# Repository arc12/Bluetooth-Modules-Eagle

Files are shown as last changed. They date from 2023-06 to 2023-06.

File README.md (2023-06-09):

# Bluetooth Modules Eagle CAD Files
"Breakout" boards designed for HM10 and HM11 Bluetooth (BT) modules and pin-equivalent clones (etc) based on TI CC2540/2541 SoC.

These are intended to be usable for both breadboard prototyping and as modules for "finished" items (although admittedly in a DIY concept). Unlike breakouts on the open market, it is strictly a 3.3V approach. Both modules have a 5-pin header exposing the "debug" interface pins of the CC254x which can be used for loading new firmware (see notes below) and probably for actual debugging operations with a suitable IDE. The 5-pin header is semi-detached from the rest of the board due to a milled slot so that it can be cut off if not required (but pay attention to making sure the cut copper tracks don't have short-cuts.

As a "finished" item, the concept for the two boards differs:
- For the HM11 based board, the main header is arranged such that the central 6 pins match the pinout of popular USB-Serial boards based on CH340. The intention is that the BT board is plugged into the same header as is used for loading the firmware and is used to provide wireless serial output from a separate MCU and its associated sensors, or to provide serial input for control etc. Notice that there is a cuttable (and re-solderable) link adjacent to the header pins where the CH340 has DTR and RTS/CTS pins. Cut these if these are being used for bootloader control.
- For the HM10 based board, the scenario in mind is that the CC254x is used without a controlling MCU, with its I/O pins being used for various sensors or output connected to the main header.

Each board has one resistor and one capacitor as 1206 size SMD pads. These are optional; the capacitor is good practice for power supply and the resistor is intended for the "finished" scenarios.

## Changing Firmware
This is relevant to "clone" modules, although it may not work on all clones (definitely not if the CC254x is not genuine).

There are two fairly easy approaches:
- Using an ESP8266. See: https://github.com/Jason2866/CCLoader
- Using a Raspberry Pi. See: https://github.com/exotulip/CC2541-programmer

There are a lot of people who have essentially re-hashed the ESP8266 instructions and published online and the arduino forum is full of various accounts of success or failure. Using the boards presented here, with 3.3V native devices such as the RPi and ESP8266 should make life easier.

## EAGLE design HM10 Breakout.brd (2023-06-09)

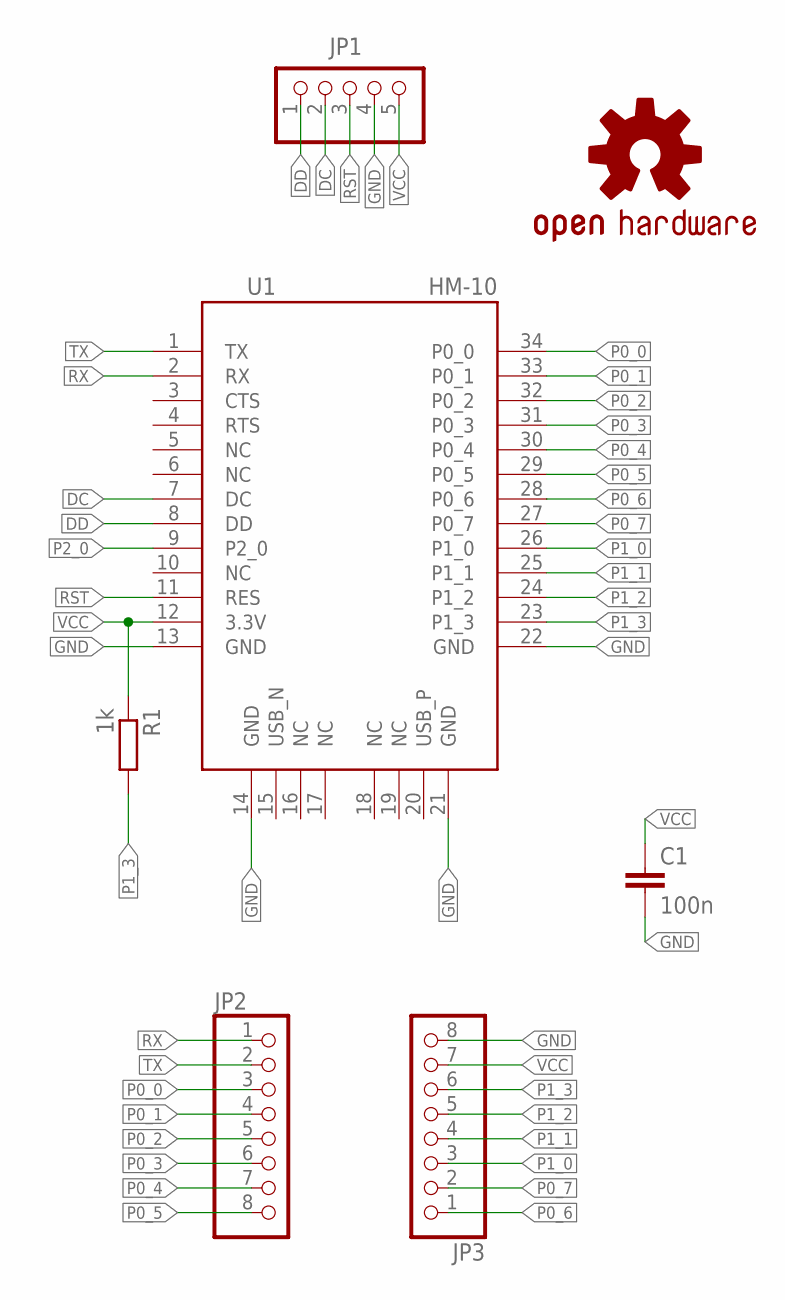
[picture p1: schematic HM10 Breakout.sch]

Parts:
C1: 100n; 1206
JP1: PINHD-1X5; 1X05
JP2, JP3: PINHD-1X8; 1X08
LOGO1: OSHW-LOGOM; OSHW-LOGO-M
R1: 1k; R1206
U1: HM-10

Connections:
DC: JP1.2, U1.7 (DC)
DD: JP1.1, U1.8 (DD)
GND: C1.2, JP1.4, JP3.8, U1.13 (GND), U1.14 (GND), U1.21 (GND), U1.22 (GND)
P0_0: JP2.3, U1.34 (P0_0)
P0_1: JP2.4, U1.33 (P0_1)
P0_2: JP2.5, U1.32 (P0_2)
P0_3: JP2.6, U1.31 (P0_3)
P0_4: JP2.7, U1.30 (P0_4)
P0_5: JP2.8, U1.29 (P0_5)
P0_6: JP3.1, U1.28 (P0_6)
P0_7: JP3.2, U1.27 (P0_7)
P1_0: JP3.3, U1.26 (P1_0)
P1_1: JP3.4, U1.25 (P1_1)
P1_2: JP3.5, U1.24 (P1_2)
P1_3: JP3.6, R1.2, U1.23 (P1_3)
P2_0: U1.9 (P2_0)
RST: JP1.3, U1.11 (RES)
RX: JP2.1, U1.2 (RX)
TX: JP2.2, U1.1 (TX)
VCC: C1.1, JP1.5, JP3.7, R1.1, U1.12 (3.3V)

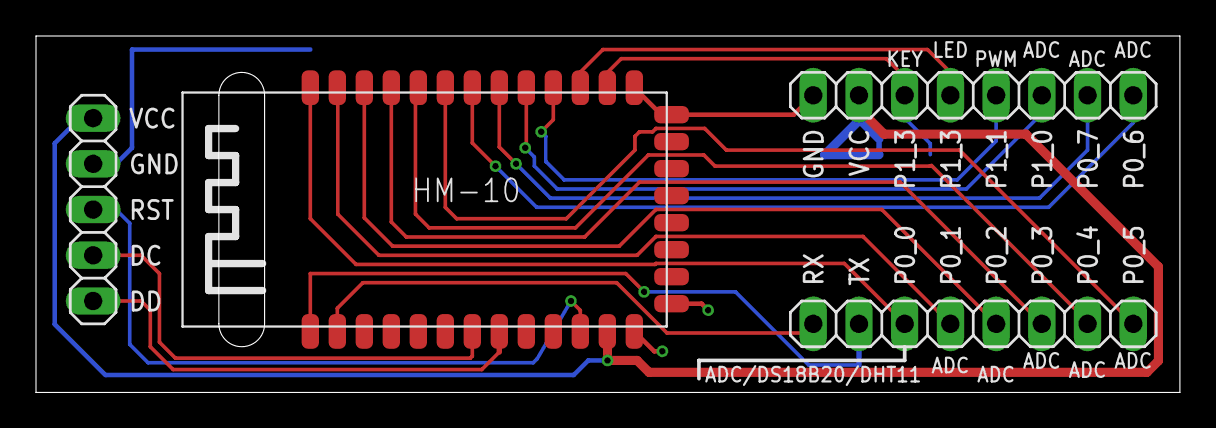
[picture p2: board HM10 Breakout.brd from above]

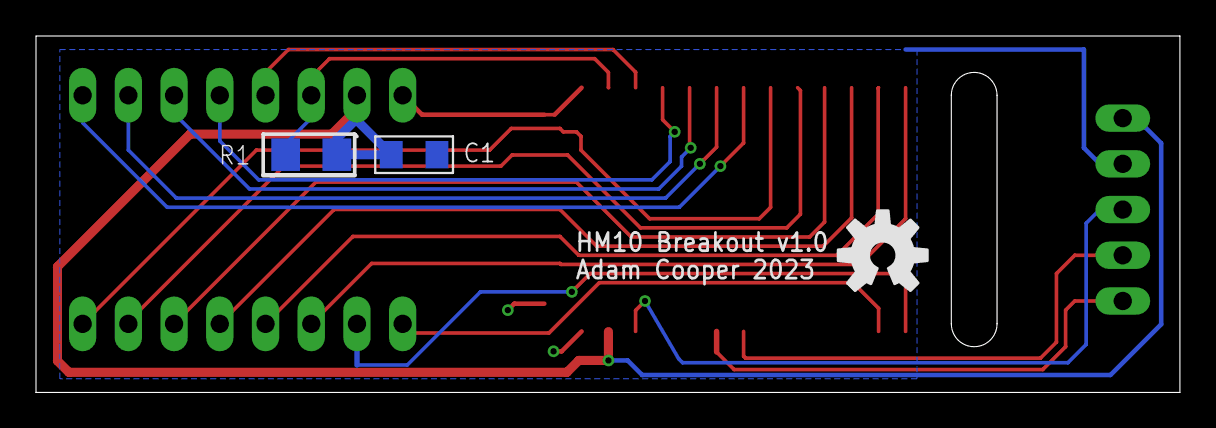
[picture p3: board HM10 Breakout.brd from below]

Board: 2 copper layers, 63.6 x 19.8 mm, 7 parts (3 on the bottom side), 19 nets.

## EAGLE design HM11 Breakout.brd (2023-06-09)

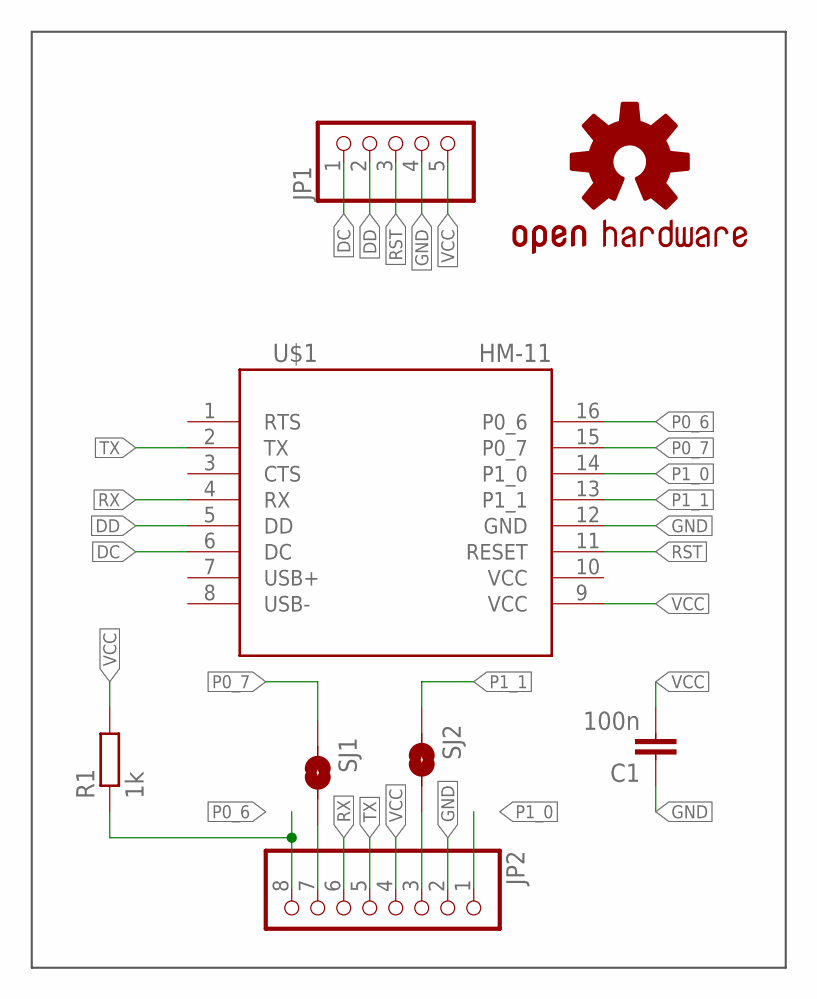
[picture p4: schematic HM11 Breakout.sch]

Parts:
C1: 100n; 1206
JP1: PINHD-1X5; 1X05
JP2: PINHD-1X8; 1X08
LOGO1: OSHW-LOGOM; OSHW-LOGO-M
R1: 1k; R1206
SJ1, SJ2: SOLDERJUMPERTRACE; SJ_2S-TRACE
U$1: HM-11

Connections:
DC: JP1.1, U$1.6 (DC)
DD: JP1.2, U$1.5 (DD)
GND: C1.1, JP1.4, JP2.2, U$1.12 (GND)
unnamed: JP2.7, SJ1.1
unnamed: JP2.3, SJ2.1
P0_6: JP2.8, R1.1, U$1.16 (P0_6)
P0_7: SJ1.2, U$1.15 (P0_7)
P1_0: JP2.1, U$1.14 (P1_0)
P1_1: SJ2.2, U$1.13 (P1_1)
RST: JP1.3, U$1.11 (RESET)
RX: JP2.6, U$1.4 (RX)
TX: JP2.5, U$1.2 (TX)
VCC: C1.2, JP1.5, JP2.4, R1.2, U$1.9 (VCC)

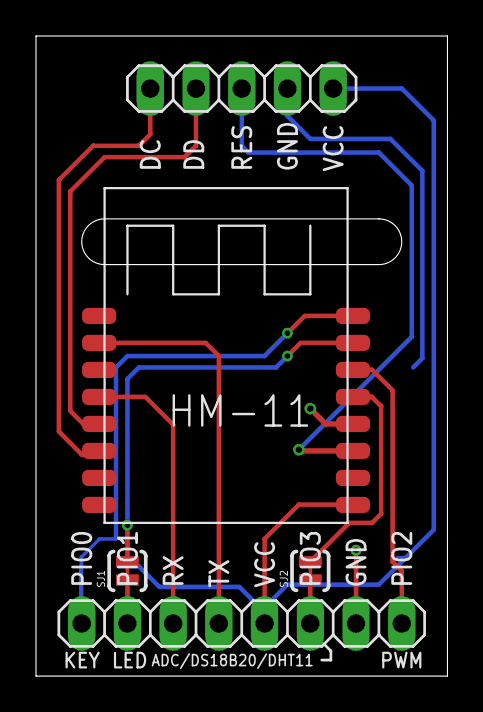
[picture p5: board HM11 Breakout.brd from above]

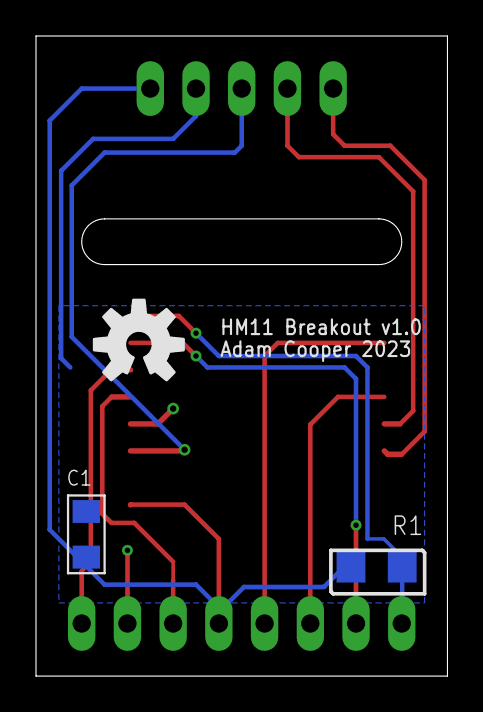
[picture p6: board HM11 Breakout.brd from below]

Board: 2 copper layers, 22.9 x 35.6 mm, 8 parts (3 on the bottom side), 13 nets.

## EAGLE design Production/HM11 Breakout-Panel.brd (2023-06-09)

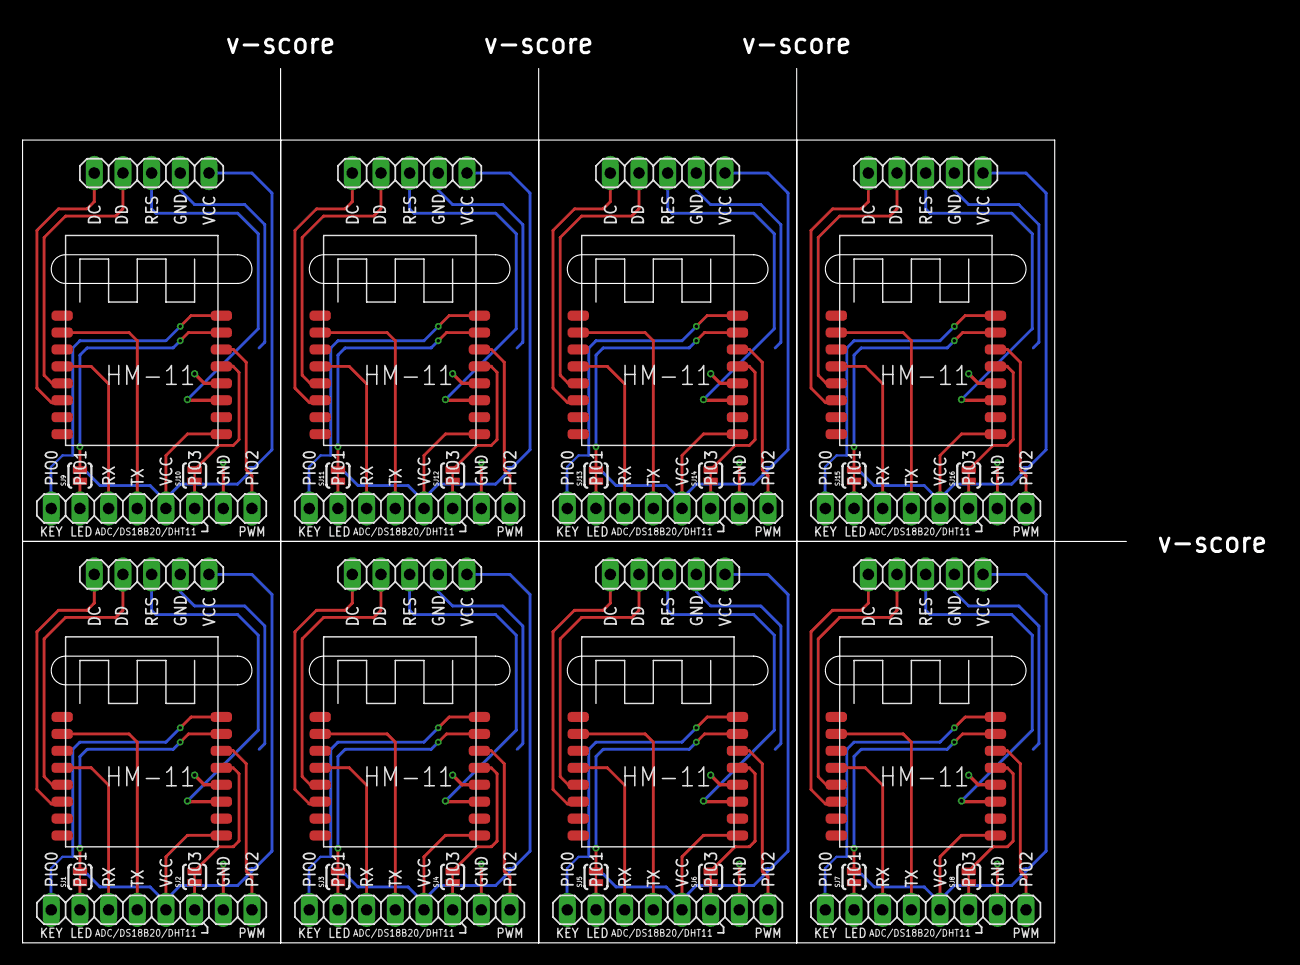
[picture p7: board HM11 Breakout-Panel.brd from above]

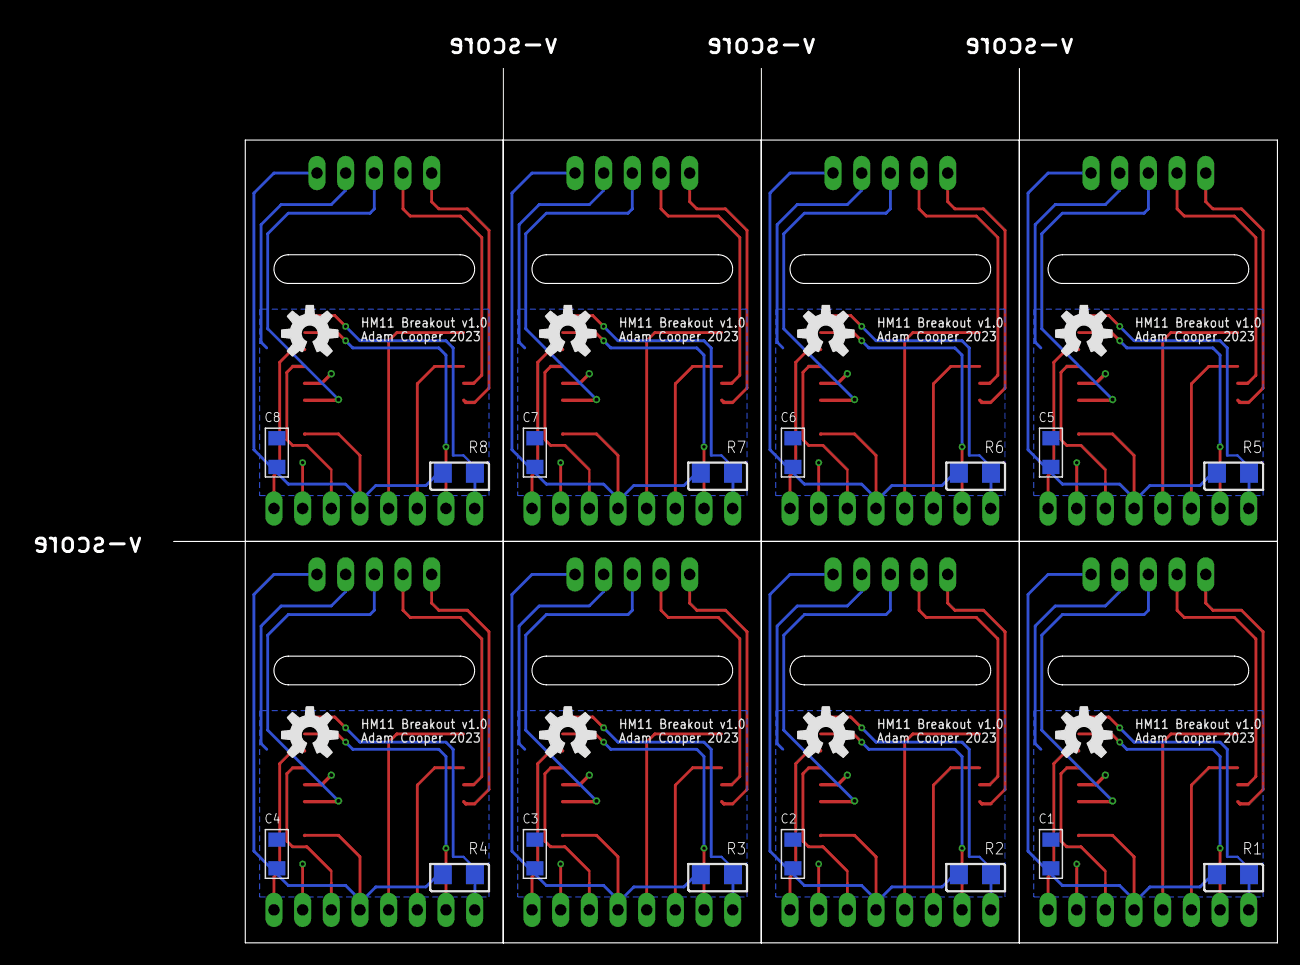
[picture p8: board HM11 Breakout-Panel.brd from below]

Board: 2 copper layers, 97.8 x 77.5 mm, 64 parts (24 on the bottom side), 104 nets.

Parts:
C1, C2, C3, C4, C5, C6, C7, C8: 100n; 1206
JP1, JP3, JP5, JP7, JP9, JP11, JP13, JP15: 1X05
JP2, JP4, JP6, JP8, JP10, JP12, JP14, JP16: 1X08
LOGO1, LOGO2, LOGO3, LOGO4, LOGO5, LOGO6, LOGO7, LOGO8: OSHW-LOGOM; OSHW-LOGO-M
R1, R2, R3, R4, R5, R6, R7, R8: 1k; R1206
SJ1, SJ2, SJ3, SJ4, SJ5, SJ6, SJ7, SJ8, SJ9, SJ10, SJ11, SJ12, SJ13, SJ14, SJ15, SJ16: SOLDERJUMPERTRACE; SJ_2S-TRACE
U$1, U$2, U$3, U$4, U$5, U$6, U$7, U$8: HM-11

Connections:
DC: JP1.1, U$1.6
DC1: JP3.1, U$2.6
DC2: JP5.1, U$3.6
DC3: JP7.1, U$4.6
DC4: JP9.1, U$5.6
DC5: JP11.1, U$6.6
DC6: JP13.1, U$7.6
DC7: JP15.1, U$8.6
DD: JP1.2, U$1.5
DD1: JP3.2, U$2.5
DD2: JP5.2, U$3.5
DD3: JP7.2, U$4.5
DD4: JP9.2, U$5.5
DD5: JP11.2, U$6.5
DD6: JP13.2, U$7.5
DD7: JP15.2, U$8.5
GND: C1.1, JP1.4, JP2.2, U$1.12
GND1: C2.1, JP3.4, JP4.2, U$2.12
GND2: C3.1, JP5.4, JP6.2, U$3.12
GND3: C4.1, JP7.4, JP8.2, U$4.12
GND4: C5.1, JP9.4, JP10.2, U$5.12
GND5: C6.1, JP11.4, JP12.2, U$6.12
GND6: C7.1, JP13.4, JP14.2, U$7.12
GND7: C8.1, JP15.4, JP16.2, U$8.12
unnamed: JP2.7, SJ1.1
unnamed: JP4.7, SJ3.1
unnamed: JP4.3, SJ4.1
unnamed: JP6.7, SJ5.1
unnamed: JP6.3, SJ6.1
unnamed: JP2.3, SJ2.1
unnamed: JP8.7, SJ7.1
unnamed: JP8.3, SJ8.1
unnamed: JP10.7, SJ9.1
unnamed: JP10.3, SJ10.1
unnamed: JP12.7, SJ11.1
unnamed: JP12.3, SJ12.1
unnamed: JP14.7, SJ13.1
unnamed: JP14.3, SJ14.1
unnamed: JP16.7, SJ15.1
unnamed: JP16.3, SJ16.1
P0_1: JP4.8, R2.1, U$2.16
P0_2: SJ3.2, U$2.15
P0_3: JP6.8, R3.1, U$3.16
P0_4: SJ5.2, U$3.15
P0_5: JP8.8, R4.1, U$4.16
P0_6: JP2.8, R1.1, U$1.16
P0_7: SJ1.2, U$1.15
P0_8: SJ7.2, U$4.15
P0_9: JP10.8, R5.1, U$5.16
P0_10: SJ9.2, U$5.15
P0_11: JP12.8, R6.1, U$6.16
P0_12: SJ11.2, U$6.15
P0_13: JP14.8, R7.1, U$7.16
P0_14: SJ13.2, U$7.15
P0_15: JP16.8, R8.1, U$8.16
P0_16: SJ15.2, U$8.15
P1_0: JP2.1, U$1.14
P1_1: SJ2.2, U$1.13
P1_2: JP4.1, U$2.14
P1_3: SJ4.2, U$2.13
P1_4: JP6.1, U$3.14
P1_5: SJ6.2, U$3.13
P1_6: JP8.1, U$4.14
P1_7: SJ8.2, U$4.13
P1_8: JP10.1, U$5.14
P1_9: SJ10.2, U$5.13
P1_10: JP12.1, U$6.14
P1_11: SJ12.2, U$6.13
P1_12: JP14.1, U$7.14
P1_13: SJ14.2, U$7.13
P1_14: JP16.1, U$8.14
P1_15: SJ16.2, U$8.13
RST: JP1.3, U$1.11
RST1: JP3.3, U$2.11
RST2: JP5.3, U$3.11
RST3: JP7.3, U$4.11
RST4: JP9.3, U$5.11
RST5: JP11.3, U$6.11
RST6: JP13.3, U$7.11
RST7: JP15.3, U$8.11
RX: JP2.6, U$1.4
RX1: JP4.6, U$2.4
RX2: JP6.6, U$3.4
RX3: JP8.6, U$4.4
RX4: JP10.6, U$5.4
RX5: JP12.6, U$6.4
RX6: JP14.6, U$7.4
RX7: JP16.6, U$8.4
TX: JP2.5, U$1.2
TX1: JP4.5, U$2.2
TX2: JP6.5, U$3.2
TX3: JP8.5, U$4.2
TX4: JP10.5, U$5.2
TX5: JP12.5, U$6.2
TX6: JP14.5, U$7.2
TX7: JP16.5, U$8.2
VCC: C1.2, JP1.5, JP2.4, R1.2, U$1.9
VCC1: C2.2, JP3.5, JP4.4, R2.2, U$2.9
VCC2: C3.2, JP5.5, JP6.4, R3.2, U$3.9
VCC3: C4.2, JP7.5, JP8.4, R4.2, U$4.9
VCC4: C5.2, JP9.5, JP10.4, R5.2, U$5.9
VCC5: C6.2, JP11.5, JP12.4, R6.2, U$6.9
VCC6: C7.2, JP13.5, JP14.4, R7.2, U$7.9
VCC7: C8.2, JP15.5, JP16.4, R8.2, U$8.9

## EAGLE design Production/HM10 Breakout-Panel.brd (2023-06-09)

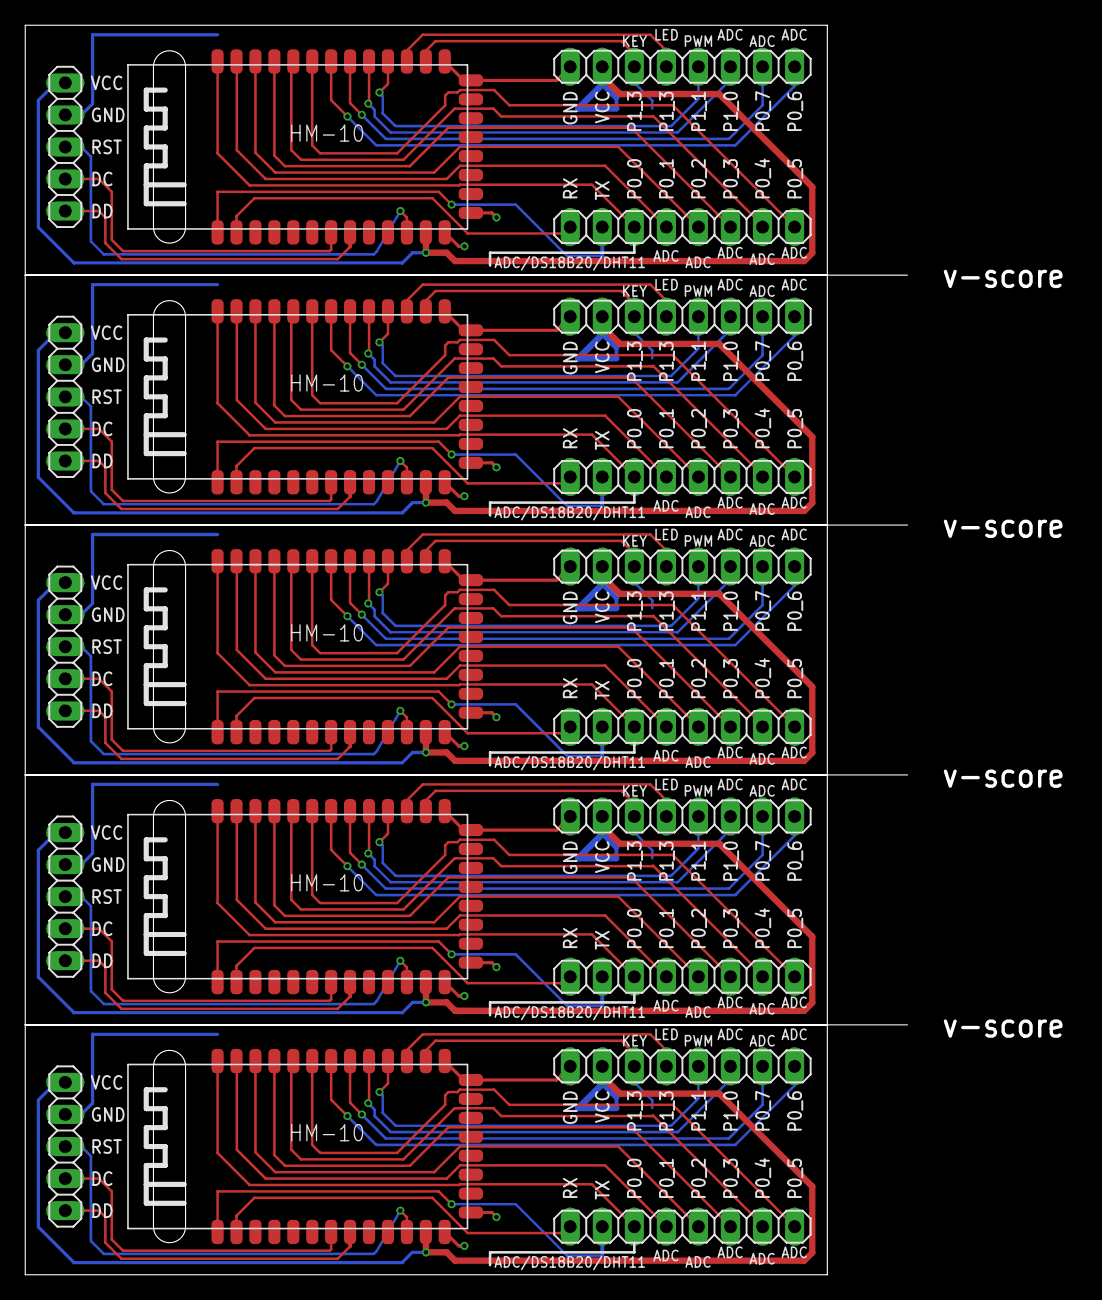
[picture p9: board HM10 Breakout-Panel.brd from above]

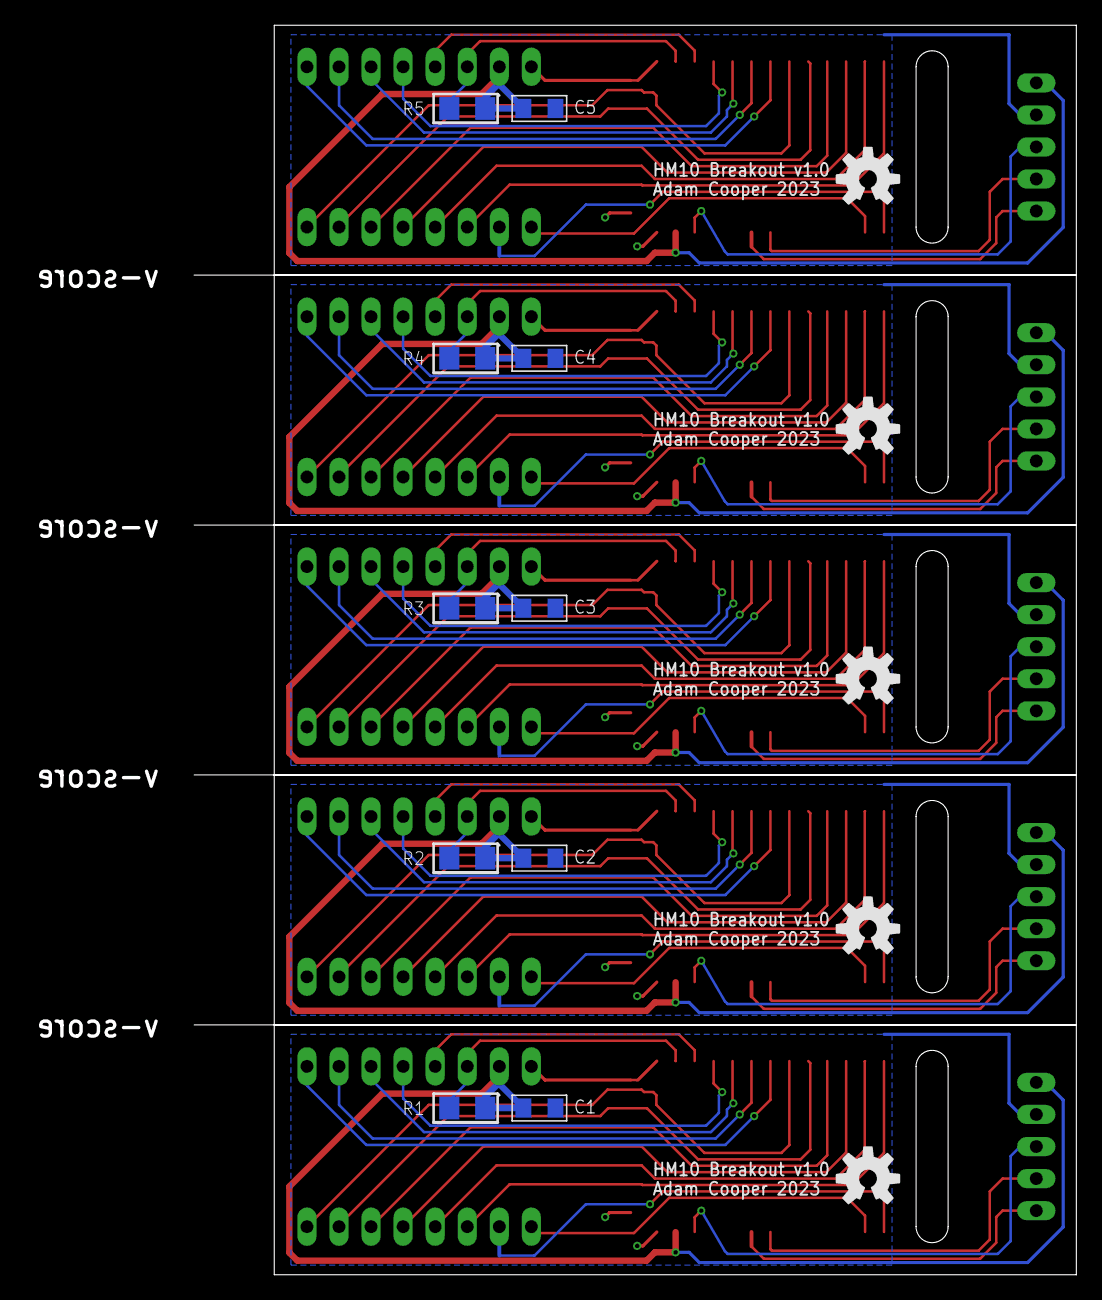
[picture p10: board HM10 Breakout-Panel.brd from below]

Board: 2 copper layers, 69.9 x 99.0 mm, 35 parts (15 on the bottom side), 95 nets.

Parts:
C1, C2, C3, C4, C5: 100n; 1206
JP1, JP4, JP7, JP10, JP13: 1X05
JP2, JP3, JP5, JP6, JP8, JP9, JP11, JP12, JP14, JP15: 1X08
LOGO1, LOGO2, LOGO3, LOGO4, LOGO5: OSHW-LOGOM; OSHW-LOGO-M
R1, R2, R3, R4, R5: 1k; R1206
U1, U2, U3, U4, U5: HM-10

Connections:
DC: JP1.2, U1.7
DC1: JP4.2, U2.7
DC2: JP7.2, U3.7
DC3: JP10.2, U4.7
DC4: JP13.2, U5.7
DD: JP1.1, U1.8
DD1: JP4.1, U2.8
DD2: JP7.1, U3.8
DD3: JP10.1, U4.8
DD4: JP13.1, U5.8
GND: C1.2, JP1.4, JP3.8, U1.13, U1.14, U1.21, U1.22
GND1: C2.2, JP4.4, JP6.8, U2.13, U2.14, U2.21, U2.22
GND2: C3.2, JP7.4, JP9.8, U3.13, U3.14, U3.21, U3.22
GND3: C4.2, JP10.4, JP12.8, U4.13, U4.14, U4.21, U4.22
GND4: C5.2, JP13.4, JP15.8, U5.13, U5.14, U5.21, U5.22
P0_0: JP2.3, U1.34
P0_1: JP2.4, U1.33
P0_2: JP2.5, U1.32
P0_3: JP2.6, U1.31
P0_4: JP2.7, U1.30
P0_5: JP2.8, U1.29
P0_6: JP3.1, U1.28
P0_7: JP3.2, U1.27
P0_8: JP5.3, U2.34
P0_9: JP5.4, U2.33
P0_10: JP5.5, U2.32
P0_11: JP5.6, U2.31
P0_12: JP5.7, U2.30
P0_13: JP5.8, U2.29
P0_14: JP6.1, U2.28
P0_15: JP6.2, U2.27
P0_16: JP8.3, U3.34
P0_17: JP8.4, U3.33
P0_18: JP8.5, U3.32
P0_19: JP8.6, U3.31
P0_20: JP8.7, U3.30
P0_21: JP8.8, U3.29
P0_22: JP9.1, U3.28
P0_23: JP9.2, U3.27
P0_24: JP11.3, U4.34
P0_25: JP11.4, U4.33
P0_26: JP11.5, U4.32
P0_27: JP11.6, U4.31
P0_28: JP11.7, U4.30
P0_29: JP11.8, U4.29
P0_30: JP12.1, U4.28
P0_31: JP12.2, U4.27
P0_32: JP14.3, U5.34
P0_33: JP14.4, U5.33
P0_34: JP14.5, U5.32
P0_35: JP14.6, U5.31
P0_36: JP14.7, U5.30
P0_37: JP14.8, U5.29
P0_38: JP15.1, U5.28
P0_39: JP15.2, U5.27
P1_0: JP3.3, U1.26
P1_1: JP3.4, U1.25
P1_2: JP3.5, U1.24
P1_3: JP3.6, R1.2, U1.23
P1_4: JP6.3, U2.26
P1_5: JP6.4, U2.25
P1_6: JP6.5, U2.24
P1_7: JP6.6, R2.2, U2.23
P1_8: JP9.3, U3.26
P1_9: JP9.4, U3.25
P1_10: JP9.5, U3.24
P1_11: JP9.6, R3.2, U3.23
P1_12: JP12.3, U4.26
P1_13: JP12.4, U4.25
P1_14: JP12.5, U4.24
P1_15: JP12.6, R4.2, U4.23
P1_16: JP15.3, U5.26
P1_17: JP15.4, U5.25
P1_18: JP15.5, U5.24
P1_19: JP15.6, R5.2, U5.23
RST: JP1.3, U1.11
RST1: JP4.3, U2.11
RST2: JP7.3, U3.11
RST3: JP10.3, U4.11
RST4: JP13.3, U5.11
RX: JP2.1, U1.2
RX1: JP5.1, U2.2
RX2: JP8.1, U3.2
RX3: JP11.1, U4.2
RX4: JP14.1, U5.2
TX: JP2.2, U1.1
TX1: JP5.2, U2.1
TX2: JP8.2, U3.1
TX3: JP11.2, U4.1
TX4: JP14.2, U5.1
VCC: C1.1, JP1.5, JP3.7, R1.1, U1.12
VCC1: C2.1, JP4.5, JP6.7, R2.1, U2.12
VCC2: C3.1, JP7.5, JP9.7, R3.1, U3.12
VCC3: C4.1, JP10.5, JP12.7, R4.1, U4.12
VCC4: C5.1, JP13.5, JP15.7, R5.1, U5.12

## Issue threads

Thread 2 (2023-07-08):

HM-11 (panelised) Device numbering

arc12, 2023-07-08:
Sub-issue 1: The device numbering increments between panels.
I suspect this was just user error when generating and that following the proper procedure would fix,

Sub-issue 2: the solder jumpers for PIO1 and 3 have redundant "SJx" silk.

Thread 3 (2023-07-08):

HM-10 (panelised) - Device numbering

arc12, 2023-07-08:
The device names increment. See #3 sub-issue 1.

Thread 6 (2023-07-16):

Consider variant HM-10 with P1.4-P1.7 broken out

arc12, 2023-07-16:
These are the SPI pins.
Required e.g. for the CCDebugger-based packet sniffer.

Could possibly place as header pins off the top face, directly adjecent to the HM-10 module pads for the SPI.

arc12, 2023-07-16:
Not possible - these Soc pins are not connected to module pads!
The module pads 16-19 are simply not connected!

Closed 2023-07-16.

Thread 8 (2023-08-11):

HM-10 silk error ADC

arc12, 2023-08-11:
no ADC on PIO3 = P1.0

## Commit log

2023-06-08 Initial boards. finished but for superficial stuff
    [HM10 Breakout.brd, HM10 Breakout.sch, HM11 Breakout.brd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]
2023-06-09 add version & attribution text
    [HM10 Breakout.brd, HM10 Breakout.sch, HM11 Breakout.brd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]
2023-06-09 panelised boards
    [HM10 Breakout-Panel.brd, HM11 Breakout-Panel.brd]
2023-06-09 Add Gerber files for v1.0 as produced for Seeed Studio
    [HM10 Breakout-Panel.GBL, HM10 Breakout-Panel.GBO, HM10 Breakout-Panel.GBP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]
2023-06-09 Add ReadMe info on using the boards
